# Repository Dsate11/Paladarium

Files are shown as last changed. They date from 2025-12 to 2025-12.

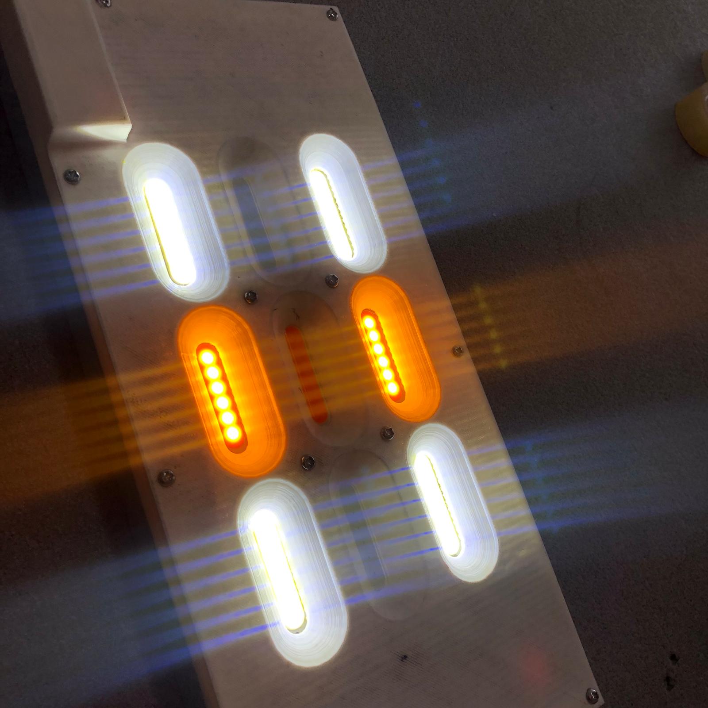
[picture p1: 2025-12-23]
images/leds_encendidos.jpg

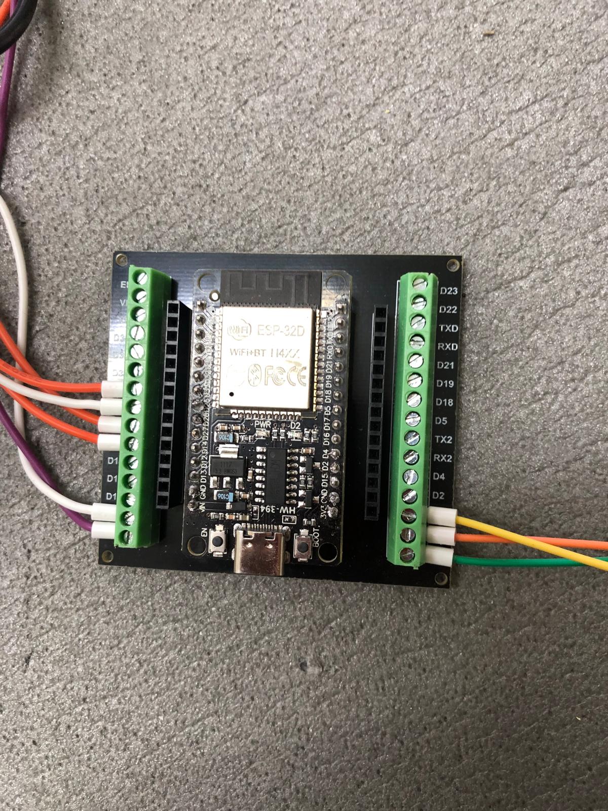
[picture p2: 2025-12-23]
images/f64968c0-9295-499c-b41d-dae9b5a2a1e8.jpg

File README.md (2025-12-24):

# 🌿 Paladarium - Sistema de Ecosistema Automatizado

Un proyecto de automatización para paladarium/terrario con control de clima, iluminación y monitoreo integrado con Home Assistant.

## 📋 Descripción

Este proyecto implementa un sistema completo de control y monitoreo para un paladarium, utilizando ESP32 y sensores diversos para mantener condiciones óptimas para plantas y animales. La integración con Home Assistant permite el control remoto y la visualización de datos en tiempo real.

## 🌡️ Sistema de Control de Clima

El paladarium cuenta con un sistema automatizado de control climático que gestiona temperatura, humedad y efectos de agua mediante sensores y actuadores conectados a un ESP32.

### Componentes del Sistema
- **Sensor DHT11**: Monitoreo de temperatura y humedad ambiental
- **Bombas de Agua**: 
  - Bomba de lluvia para simulación de precipitación
  - Bomba de cascada para circulación de agua
- **Relés**: Control de encendido/apagado de bombas y otros dispositivos

### Documentación Técnica Detallada
Para información completa sobre conexiones, configuración y diagramas de cableado, consulta la documentación en la carpeta `ecosistema_paladario/`:

- 📌 [**ESP32_PINOUT.md**](ecosistema_paladario/ESP32_PINOUT.md) - Asignación completa de pines del ESP32
- 📌 [**PINOUT.md**](ecosistema_paladario/PINOUT.md) - Diagrama general de conexiones
- 📌 [**CONEXIONES_DHT11.md**](ecosistema_paladario/CONEXIONES_DHT11.md) - Guía específica de conexión del sensor DHT11
- 📌 [**README_SISTEMA.md**](ecosistema_paladario/README_SISTEMA.md) - Descripción completa del sistema
- 📌 [**CONFIGURACION_WIFI_HA.md**](ecosistema_paladario/CONFIGURACION_WIFI_HA.md) - Configuración de WiFi y Home Assistant

## ✨ Características Futuras

- Sistema de alimentación automatizado
- Cámara para monitoreo visual
- Sistema de riego por goteo
- Control de CO2
- Análisis de datos históricos y predicciones

## 🚀 Tecnologías Utilizadas

- ESP32
- Home Assistant
- ESPHome
- Sensores DHT11
- Relés para control de dispositivos
- MQTT para comunicación

## 📦 Instalación

(Instrucciones de instalación pendientes)

## 🤝 Contribuciones

Las contribuciones son bienvenidas. Por favor, abre un issue o pull request para sugerencias o mejoras.

## 📄 Licencia

Este proyecto está bajo licencia MIT.

---

**Nota**: Este es un proyecto en desarrollo activo. La documentación y características se actualizan regularmente.

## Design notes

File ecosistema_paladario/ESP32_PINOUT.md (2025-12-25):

# Pinout ESP32 — Paladarium

## Tabla resumen

| Pin ESP32 | Nombre simbólico (código) | Función hardware |
|---|---|---|
| D33 | CALEFACCION_GPIO | Relé 4 (Calefacción) |
| D25 | BOMBA_LLUVIA_GPIO | Relé 1 (Bomba de lluvia) |
| D26 | BOMBA_CASCADA_GPIO | Relé 2 (Bomba cascada) |
| D27 | VENTILADOR_GPIO | Relé 3 (Ventilador) |
| D15 | DHT_GPIO | Sensor DHT11 |

---

## Diagrama de conexiones (visual)

```
                                    +----------------------+
                                    |     ESP32 DevKit     |
                          ________  +----------------------+
                         |        |  GPIO    | Dispositivo 
            Rele 4 <---- |  D33   | -------- | CALEFACCION  
            Rele 1 <---- |  D25   | -------- | BOMBA LLUVIA 
            Rele 2 <---- |  D26   | -------- | BOMBA CASCADA
            Rele 3 <---- |  D27   | -------- | VENTILADOR   
             DHT11 <---- |  D15   | -------- | SENSOR DHT11 
                         |________|
```

> **Nota:** Utiliza la referencia de pinout físico del modelo de ESP32 devkit que utilices para ubicar físicamente los GPIO referenciados.

---

## Recomendaciones y Advertencias

- Verifica la capacidad de corriente de cada pin antes de realizar cualquier conexión de carga.
- Los pines destinados a relés deben ser empleados con módulos de relé que admitan el voltaje de control TTL (3.3V en ESP32).
- Evita usar los pines listados para otras funciones para prevenir conflictos o comportamientos inesperados.
- Antes de energizar el sistema, comprueba dos veces las conexiones para evitar cortocircuitos o daños a la placa.
- No conectes cargas inductivas o de alto voltaje directamente al ESP32. Utiliza siempre relés o drivers adecuados.
- Consulta la hoja de datos de tu versión de la placa ESP32 y del sensor DHT11 para confirmar compatibilidades y conexiones de alimentación.

---

## Coincidencia con el código (src/main.c)

La definición de pines en `src/main.c` debe mantener la correlación 1 a 1 con la tabla presente en este documento. Cualquier modificación DEBE reflejarse en ambos lados para evitar inconsistencias o fallos de operación.

Ejemplo de definición:

```c
#define CALEFACCION_GPIO      33
#define BOMBA_LLUVIA_GPIO     25
#define BOMBA_CASCADA_GPIO    26
#define VENTILADOR_GPIO       27
#define DHT_GPIO              15
```

---

## Notas adicionales
- Ante cualquier duda sobre cambios de hardware, actualiza este documento junto con el firmware.
- Realiza pruebas funcionales antes de la puesta en marcha definitiva del paladarium.

---

Autor: Dsate11
Última actualización: 2025-12-25

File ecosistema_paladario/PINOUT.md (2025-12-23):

# 📌 PINOUT DETALLADO - Sistema Paladario ESP32

## 🔌 Conexiones del Sistema

### **Sensor DHT11 (Temperatura y Humedad)**

**Módulo de 3 pines (con resistencia pull-up integrada):**

**Cómo identificar los pines:**

1. **Por serigrafía en la PCB** (lo más común):
   - Busca las letras impresas en la tarjeta: `+`, `OUT`/`S`/`DATA`, `-`/`GND`
   - O pueden estar como: `VCC`, `DATA`, `GND`

2. **Por posición física** (vista desde el frente del sensor):
   ```
   ┌─────────────┐
   │   DHT11     │  ← Sensor azul con rejilla
   │  (rejilla)  │
   └─────────────┘
   │   │   │   │
   │   │   │   └─ Pin 4: GND (puede estar NC - no conectado)
   │   │   └───── Pin 3: NC (No Conectar) o no existe
   │   └───────── Pin 2: DATA (señal)
   └───────────── Pin 1: VCC (+)
   ```

3. **En módulos de 3 pines** (tarjeta verde/azul):
   ```
   Tarjeta PCB vista de frente:
   
   [+]  [OUT]  [-]     ← Serigrafía común
    │     │     │
   VCC  DATA  GND
   ```
   
   O también puede ser:
   ```
   [S]  [VCC]  [GND]   ← Otra disposición común
    │     │      │
   DATA  VCC   GND
   ```

**Conexión segura al ESP32:**
```
Módulo DHT11   →    ESP32
---------------------------------
+ / VCC        →    3.3V o 5V
OUT / S / DATA →    GPIO 4
- / GND        →    GND
```

**Nota:** Este módulo ya incluye la resistencia pull-up en la tarjeta, **NO necesitas agregar resistencia externa**

**🔍 Si no hay marcas visibles:**
- Con un multímetro, mide continuidad entre los pines del módulo y el sensor DHT11
- El pin GND del módulo debe tener continuidad con el pin 4 del sensor DHT11
- El pin VCC del módulo debe tener continuidad con el pin 1 del sensor DHT11

**Sensor DHT11 de 4 pines (sin módulo):**
```
DHT11 Sensor   →    Conexión
---------------------------------
VCC (Pin 1)    →    3.3V o 5V
DATA (Pin 2)   →    GPIO 4 + resistencia 10kΩ a VCC
NC (Pin 3)     →    No conectar
GND (Pin 4)    →    GND
```

---

### **Relé Bomba de Lluvia**
```
Módulo Relé    →    ESP32
---------------------------------
VCC            →    5V (VIN)
GND            →    GND
IN (Signal)    →    GPIO 25
```
**Conexión de la bomba:**
- COM (Común) → Cable de fase (220V) o positivo (12V)
- NO (Normalmente Abierto) → Bomba
- La bomba completa el circuito con Neutro (220V) o GND (12V)

---

### **Relé Bomba de Cascada**
```
Módulo Relé    →    ESP32
---------------------------------
VCC            →    5V (VIN)
GND            →    GND
IN (Signal)    →    GPIO 26
```
**Conexión de la bomba:**
- COM (Común) → Cable de fase (220V) o positivo (12V)
- NO (Normalmente Abierto) → Bomba
- La bomba completa el circuito con Neutro (220V) o GND (12V)

---

## 🔧 Resumen de Pines ESP32 Utilizados

| Pin GPIO | Función | Tipo | Descripción |
|---|---|---|---|
| GPIO 4 | Sensor DHT11 DATA | INPUT | Lectura temperatura/humedad |
| GPIO 25  | Control Bomba Lluvia | OUTPUT  | Activa/desactiva relé lluvia |
| GPIO 26  | Control Bomba Cascada | OUTPUT  | Activa/desactiva relé cascada |
| 3.3V | Alimentación sensores | POWER | Para DHT11 |
| 5V (VIN) | Alimentación relés | POWER | Para módulos relé |
| GND | Tierra común | GROUND  | Compartida todos los componentes |

---

## 🎨 Diagrama de Conexión Simplificado

```
                    ┌─────────────────┐
                    │     ESP32       │
                    │  DevKit V4      │
                    └─────────────────┘
                            │
        ┌───────────────────┼───────────────────┐
        │                   │                   │
    GPIO 4             GPIO 25            GPIO 26
        │                   │                   │
   ┌────▼────┐         ┌────▼────┐        ┌────▼────┐
   │ DHT11   │         │ RELÉ 1  │        │ RELÉ 2  │
   │ Temp/Hum│         │ LLUVIA  │        │ CASCADA │
   └─────────┘         └────┬────┘        └────┬────┘
                            │                  │
                       ┌────▼────┐        ┌────▼────┐
                       │ BOMBA   │        │ BOMBA   │
                       │ LLUVIA  │        │ CASCADA │
                       └─────────┘        └─────────┘
```

---

## ⚠️ ADVERTENCIAS DE SEGURIDAD

### **Si usas 220V AC:**
1. ⚡ **PELIGRO:** Desconecta siempre la alimentación antes de manipular
2. Usa módulos relés con optoacoplador para aislamiento
3. Verifica que los relés soporten la corriente de tus bombas
4. Instala en caja eléctrica adecuada con protección IP65+ para humedad
5. Considera usar un interruptor diferencial (GFCI/RCD)

### **Si usas 12V DC:**
1. Mucho más seguro para ambientes húmedos
2. Usa fuente de alimentación de capacidad suficiente
3. Verifica polaridad correcta en las bombas
4. Los relés también deben soportar la corriente DC

---

## 🔋 Alimentación del Sistema

**Opción 1 - USB:**
- ESP32 alimentado por cable USB (5V)
- Limitado a corrientes bajas en los GPIOs
- Los relés necesitan fuente externa de 5V

**Opción 2 - Fuente Externa:**
- Alimentar VIN con 5-12V DC regulados
- Permite mayor corriente para módulos adicionales
- Compartir GND común entre ESP32 y fuente

---

## 📝 Notas Adicionales

- Los GPIOs del ESP32 entregan **3.3V lógico**
- Corriente máxima por pin: **40mA** (recomendado: 20mA)
- Los módulos relé suelen necesitar **5V** y ~70-80mA
- El DHT11 consume aproximadamente **2.5mA** en standby
- Pines GPIO 25 y 26 son seguros para usar (no tienen funciones especiales críticas)
- GPIO 4 también es seguro (no afecta el boot del ESP32)

---

## 🛠️ Lista de Materiales

| Cantidad | Componente | Especificaciones |
|---|---|---|
| 1 | ESP32 DevKit V4 | 30 pines |
| 1 | Módulo DHT11 | Temp/Humedad, 3 pines |
| 2 | Módulo Relé 1 canal | 5V, optoacoplado |
| 2 | Bomba de agua sumergible | 12V o 220V según diseño |
| 1 | Fuente de alimentación | 5V/2A o 12V/2A |
| - | Cables dupont/jumper | Macho-hembra |
| - | Protoboard o PCB | Para montaje |

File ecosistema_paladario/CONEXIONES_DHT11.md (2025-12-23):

# 🔌 ESQUEMA DE CONEXIONES - DHT11 + ESP32

## 📋 Módulo DHT11 de 3 Pines

```
Vista del módulo DHT11 (mirando de frente al sensor azul):

┌─────────────────────────┐
│   Módulo DHT11 PCB      │
│   ┌───────────────┐     │
│   │   DHT11       │     │  ← Sensor azul con rejilla
│   │  (rejilla)    │     │
│   └───────────────┘     │
│                         │
└─────────────────────────┘
   │      │      │
   │      │      └─── [-] GND    → Color cable: NEGRO o MARRÓN
   │      └────────── [OUT] DATA → Color cable: AMARILLO o VERDE
   └───────────────── [+] VCC    → Color cable: ROJO

Serigrafía común en el módulo:
┌───┬─────┬─────┐
│ + │ OUT │  -  │
└───┴─────┴─────┘
 o también:
┌─────┬──────┬─────┐
│ VCC │ DATA │ GND │
└─────┴──────┴─────┘
```

---

## 🔧 ESP32 DevKit V4 - Vista de Pines

```
ESP32 DevKit V4 (30 pines)
Puerto USB hacia ARRIBA ↑

Lado IZQUIERDO          Lado DERECHO
════════════════        ════════════════
3V3  ←─ VCC DHT11      GND
EN                      GPIO 23
GPIO 36 (VP)           GPIO 22
GPIO 39 (VN)           GPIO 1 (TX0)
GPIO 34                 GPIO 3 (RX0)
GPIO 35                 GPIO 21
GPIO 32                 GPIO 19
GPIO 33 ← CALEFACCIÓN  GPIO 18
GPIO 25 ← BOMBA LLUVIA GPIO 5
GPIO 26 ← BOMBA CASCA. GPIO 17
GPIO 27 ← VENTILADOR   GPIO 16
GPIO 14                 GPIO 4  ←─ DATA DHT11 ⭐
GPIO 12                 GPIO 0
GPIO 13                 GPIO 2  ←─ (prueba alternativa)
GND  ←─ GND DHT11      GPIO 15
VIN                     GND
```

---

## ✅ CONEXIÓN CORRECTA

```
┌──────────────────────┐              ┌──────────────────────┐
│  MÓDULO DHT11        │              │    ESP32 DevKit V4   │
│                      │              │                      │
│  ┌────────────┐      │              │                      │
│  │  DHT11     │      │              │      [USB]           │
│  │ (sensor)   │      │              │       ___            │
│  └────────────┘      │              │      |   |           │
│                      │              │                      │
│   [+]  [OUT]  [-]    │              │                      │
│    │     │     │     │              │                      │
└────┼─────┼─────┼─────┘              └──────────────────────┘
     │     │     │                          │     │     │
     │     │     └──────────────────────────┤     │     │
     │     │         CABLE NEGRO/MARRÓN     │     │     │
     │     │                               GND    │     │
     │     │                                      │     │
     │     └────────────────────────────────────┐ │     │
     │              CABLE AMARILLO/VERDE        │ │     │
     │                                       GPIO 4     │
     │                                          │ │     │
     └──────────────────────────────────────────┼─┤     │
                  CABLE ROJO                    │ │     │
                                               3V3 │     │
                                                  │     │
                                                 GND   3V3
```

---

## 🔍 VERIFICACIÓN DE CONEXIONES

### ✓ Lista de verificación:

1. **Cable ROJO (VCC)**
   - Desde pin [+] del DHT11
   - Hasta pin **3V3** del ESP32 (lado izquierdo, arriba del todo)
   - ⚠️ NO usar 5V, usar 3.3V

2. **Cable NEGRO/MARRÓN (GND)**
   - Desde pin [-] del DHT11
   - Hasta pin **GND** del ESP32 (hay varios, usa el del lado izquierdo cerca del 3V3)

3. **Cable AMARILLO/VERDE (DATA)**
   - Desde pin [OUT] o [DATA] del DHT11
   - Hasta pin **GPIO 4** del ESP32 (lado derecho, posición 12 desde abajo)
   - ⚠️ Este es el cable que está dando problemas

---

## ⚠️ ERRORES COMUNES

### ❌ Error 1: Pines invertidos
```
INCORRECTO:
DHT11 [-] → ESP32 3V3   ✗ MAL!
DHT11 [+] → ESP32 GND   ✗ MAL!
```

### ❌ Error 2: DATA conectado a GND
```
Tu problema actual:
DHT11 [OUT] → hace corto con GND
Resultado: Pin siempre en LOW
```

### ❌ Error 3: VCC sin conectar
```
DHT11 [+] → sin conexión
Resultado: Pin siempre en HIGH, no responde
```

---

## 🔧 DIAGNÓSTICO CON MULTÍMETRO

### Con el DHT11 conectado al ESP32 encendido:

1. **Medir voltaje VCC:**
   ```
   Multímetro en modo DC Voltaje
   Punta ROJA  → Pin [+] del DHT11
   Punta NEGRA → Pin [-] del DHT11
   
   Debería leer: 3.3V ± 0.1V
   Si lee 0V: VCC no conectado
   ```

2. **Medir voltaje DATA en reposo:**
   ```
   Multímetro en modo DC Voltaje
   Punta ROJA  → Pin [OUT] del DHT11
   Punta NEGRA → Pin [-] del DHT11
   
   Debería leer: 3.3V (por pull-up)
   Si lee 0V: DATA en corto con GND ← TU PROBLEMA
   ```

3. **Verificar continuidad (con ESP32 APAGADO):**
   ```
   Multímetro en modo CONTINUIDAD (beep)
   
   TEST 1:
   Punta 1 → Pin [OUT] del DHT11
   Punta 2 → Pin [-] del DHT11
   
   NO debe hacer BEEP (no debe haber continuidad)
   Si hace BEEP: Hay cortocircuito ← TU PROBLEMA
   
   TEST 2:
   Punta 1 → Pin [+] del DHT11
   Punta 2 → Pin [-] del DHT11
   
   NO debe hacer BEEP
   Si hace BEEP: Cortocircuito VCC-GND
   ```

---

## 🔨 SOLUCIÓN AL PROBLEMA ACTUAL

### Tu sensor muestra: **Pin en LOW permanente**

**Causa:** El pin DATA está en cortocircuito con GND

**Posibles soluciones:**

1. **Revisar soldadura en el módulo DHT11:**
   - ¿Hay un puente de estaño entre pines OUT y GND?
   - Dessoldar y volver a soldar con cuidado

2. **Verificar el cable DATA:**
   - ¿El aislante está dañado?
   - ¿Toca algún otro cable o componente?

3. **Probar con cables diferentes:**
   - Puede que el cable tenga daño interno

4. **Reemplazar el sensor DHT11:**
   - El sensor puede estar dañado internamente

---

## 📸 FOTO DE REFERENCIA DE PINES

```
Módulo DHT11 típico visto desde arriba:

     ╔════════════════╗
     ║  DHT11 MODULE  ║
     ║  ╔══════════╗  ║
     ║  ║ ░░░░░░░░ ║  ║  ← Rejilla del sensor
     ║  ║ ░░DHT11░ ║  ║
     ║  ║ ░░░░░░░░ ║  ║
     ║  ╚══════════╝  ║
     ║                ║
     ║  +   OUT   -   ║  ← Serigrafía
     ╚════════════════╝
        │    │    │
      ROJO AMARI NEGRO
      3V3  GPIO4  GND
```

---

## 🎯 CÓDIGO ACTUAL

El código actual está configurado para **GPIO 2** (prueba).

Para volver a GPIO 4 (correcto según hardware), cambiar en `main.c`:
```c
#define DHT_GPIO 4  // Pin correcto según documentación
```

---

## 📞 PRÓXIMOS PASOS

1. ✓ Apaga el ESP32
2. ✓ Desconecta el cable DATA (amarillo)
3. ✓ Mide con multímetro:
   - Continuidad entre DATA y GND del módulo DHT11
   - Voltaje entre VCC y GND (debería ser 3.3V con ESP32 encendido)
4. ✓ Si hay cortocircuito, revisa la soldadura del módulo
5. ✓ Reconecta y prueba de nuevo

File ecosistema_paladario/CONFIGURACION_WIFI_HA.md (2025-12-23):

# 🌐 Guía de Configuración WiFi y Home Assistant

## 📡 Configuración WiFi

### 1. Editar credenciales WiFi

Abre el archivo `src/wifi_config.h` y modifica:

```c
#define WIFI_SSID ""        // Nombre de tu red WiFi
#define WIFI_PASSWORD ""  // Contraseña de tu WiFi
```

### 2. Compilar y subir

```bash
cd "c:\Users\diego\OneDrive\Documentos\PlatformIO\Projects\ecosistema_paladario"
pio run --target upload
pio device monitor
```

### 3. Obtener la IP del ESP32

En el monitor serial verás algo como:
```
I (2345) PALADARIO: IP obtenida: 192.168.1.150
```

Anota esta IP para acceder al panel web.

---

## 🖥️ Acceso al Panel Web

### Desde cualquier navegador en tu red local:

```
http://192.168.1.150
```
(Usa la IP que obtuviste en el paso anterior)

### Características del Panel Web:

✅ **Ver en tiempo real:**
- Temperatura actual
- Humedad actual
- Estado de bombas (ON/OFF)

✅ **Controlar:**
- Encender/apagar bomba de lluvia con un click
- Encender/apagar bomba de cascada con un click

✅ **Auto-actualización:**
- La página se recarga cada 10 segundos automáticamente

---

## 🏠 Integración con Home Assistant

### Prerequisitos:

1. **Tener Home Assistant instalado y funcionando**
2. **MQTT Broker configurado** (Mosquitto addon recomendado)

### Paso 1: Configurar MQTT en Home Assistant

#### Instalar Mosquitto Broker:

1. Ve a `Settings` → `Add-ons` → `Add-on Store`
2. Busca **"Mosquitto broker"**
3. Click en `Install`
4. Una vez instalado, ve a la pestaña `Configuration`
5. Habilita estas opciones:
   ```yaml
   logins:
     - username: homeassistant
       password: tu_password_mqtt
   ```
6. Click en `Save` y luego `Start`

#### Configurar integración MQTT:

1. Ve a `Settings` → `Devices & Services`
2. Click en `Add Integration`
3. Busca **"MQTT"**
4. Configura:
   - Broker: `localhost` (o la IP de tu Home Assistant)
   - Port: `1883`
   - Username: `homeassistant`
   - Password: `tu_password_mqtt`

### Paso 2: Configurar el ESP32

Edita `src/wifi_config.h`:

```c
#define MQTT_BROKER "192.168.1.100"    // IP de tu Home Assistant
#define MQTT_PORT 1883
#define MQTT_USER "homeassistant"      // Usuario MQTT
#define MQTT_PASS "tu_password_mqtt"   // Contraseña MQTT
```

### Paso 3: Compilar y subir

```bash
pio run --target upload
```

### Paso 4: Verificar en Home Assistant

Después de unos segundos, deberías ver automáticamente en Home Assistant:

**Dispositivos detectados:**
- 🌡️ **Paladario Temperatura** (sensor)
- 💧 **Paladario Humedad** (sensor)
- 💦 **Bomba Lluvia** (switch)
- 🌊 **Bomba Cascada** (switch)

**¿Dónde encontrarlos?**
1. Ve a `Settings` → `Devices & Services`
2. Click en `MQTT`
3. Deberías ver un dispositivo llamado **"Paladario"**

---

## 🎨 Crear Tarjeta en Home Assistant

### Dashboard personalizado:

```yaml
type: vertical-stack
cards:
  - type: entities
    title: 🌿 Paladario
    entities:
      - entity: sensor.paladario_temperatura
        name: Temperatura
        icon: mdi:thermometer
      - entity: sensor.paladario_humedad
        name: Humedad
        icon: mdi:water-percent
      - entity: switch.bomba_lluvia
        name: Bomba Lluvia
        icon: mdi:water
      - entity: switch.bomba_cascada
        name: Bomba Cascada
        icon: mdi:waterfall
  - type: history-graph
    title: Historial
    entities:
      - sensor.paladario_temperatura
      - sensor.paladario_humedad
    hours_to_show: 24
```

**Cómo agregar:**
1. Ve a tu Dashboard
2. Click en los 3 puntos (arriba derecha) → `Edit Dashboard`
3. Click en `+ Add Card`
4. Selecciona `Manual` abajo
5. Pega el código YAML anterior
6. Click en `Save`

---

## 🔧 API REST Endpoints

### Obtener estado completo:

```bash
GET http://192.168.1.150/api/status
```

**Respuesta JSON:**
```json
{
  "temperatura": 25.5,
  "humedad": 68.0,
  "bomba_lluvia": true,
  "bomba_cascada": false
}
```

### Toggle Bomba Lluvia:

```bash
GET http://192.168.1.150/api/lluvia/toggle
```

### Toggle Bomba Cascada:

```bash
GET http://192.168.1.150/api/cascada/toggle
```

---

## 📊 Tópicos MQTT

### Sensores (lectura):

```
paladario/sensor/temperatura/state    → "25.5"
paladario/sensor/humedad/state        → "68.0"
```

### Switches Estado (lectura):

```
paladario/switch/bomba_lluvia/state   → "ON" o "OFF"
paladario/switch/bomba_cascada/state  → "ON" o "OFF"
```

### Switches Comandos (escritura):

```
paladario/switch/bomba_lluvia/set     ← "ON" o "OFF"
paladario/switch/bomba_cascada/set    ← "ON" o "OFF"
```

---

## 🎯 Automatizaciones en Home Assistant

### Ejemplo 1: Notificación de temperatura alta

```yaml
automation:
  - alias: "Alerta Temperatura Alta Paladario"
    trigger:
      - platform: numeric_state
        entity_id: sensor.paladario_temperatura
        above: 30
    action:
      - service: notify.mobile_app
        data:
          title: "⚠️ Temperatura Alta"
          message: "El paladario tiene {{ states('sensor.paladario_temperatura') }}°C"
```

### Ejemplo 2: Encender lluvia automáticamente

```yaml
automation:
  - alias: "Lluvia Automática Paladario"
    trigger:
      - platform: numeric_state
        entity_id: sensor.paladario_humedad
        below: 50
    action:
      - service: switch.turn_on
        target:
          entity_id: switch.bomba_lluvia
```

### Ejemplo 3: Cascada solo de día

```yaml
automation:
  - alias: "Cascada Solo de Día"
    trigger:
      - platform: sun
        event: sunrise
    action:
      - service: switch.turn_on
        target:
          entity_id: switch.bomba_cascada
  
  - alias: "Apagar Cascada de Noche"
    trigger:
      - platform: sun
        event: sunset
    action:
      - service: switch.turn_off
        target:
          entity_id: switch.bomba_cascada
```

---

## 🔍 Solución de Problemas

### No aparece en Home Assistant:

1. **Verificar MQTT:**
   - Ve a `Settings` → `Devices & Services` → `MQTT`
   - Click en `Configure` → `Listen to a topic`
   - Escribe: `paladario/#`
   - Deberías ver mensajes llegando

2. **Verificar logs del ESP32:**
   ```bash
   pio device monitor
   ```
   Busca: `MQTT conectado` y `Descubrimiento MQTT enviado`

3. **Reiniciar Home Assistant:**
   - `Settings` → `System` → `Restart`

### No puedo acceder al panel web:

1. Verificar que estés en la misma red WiFi
2. Hacer ping a la IP del ESP32
3. Verificar firewall/router
4. Revisar logs en el monitor serial

### MQTT no conecta:

1. Verificar IP correcta del broker
2. Verificar usuario y contraseña
3. Verificar que Mosquitto esté corriendo
4. Revisar puerto 1883 abierto

---

## 📱 Aplicación Móvil Home Assistant

Con la app de Home Assistant en tu móvil puedes:

✅ Ver temperatura y humedad en tiempo real
✅ Controlar las bombas desde cualquier lugar
✅ Recibir notificaciones
✅ Widgets en pantalla de inicio
✅ Control por voz con Google Assistant/Alexa

**Descargar:**
- iOS: App Store → "Home Assistant"
- Android: Play Store → "Home Assistant"

---

## 🎉 ¡Todo Listo!

Ahora tienes:

✅ Panel web accesible desde cualquier navegador
✅ Integración completa con Home Assistant
✅ Control desde móvil
✅ Automatizaciones inteligentes
✅ Historial de datos
✅ Notificaciones

**Próximos pasos opcionales:**
- Agregar más sensores (luz, pH, etc.)
- Crear escenas personalizadas
- Integrar con Google Home/Alexa
- Agregar cámara para ver el paladario

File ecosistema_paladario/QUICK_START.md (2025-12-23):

# 🚀 QUICK START - Paladario WiFi

## 📝 Pasos Rápidos

### 1. Configurar WiFi
Edita `src/wifi_config.h`:
```c
#define WIFI_SSID "TU_RED_WIFI"
#define WIFI_PASSWORD "TU_CONTRASEÑA"
```

### 2. Subir Código
```bash
pio run --target upload
pio device monitor
```

### 3. Obtener IP
Busca en el monitor serial:
```
I (2345) PALADARIO: IP obtenida: 192.168.1.150
```

### 4. Acceder desde Navegador
```
http://192.168.1.150
```

## 🏠 Home Assistant (Opcional)

### 1. Instalar Mosquitto Broker en HA
- Settings → Add-ons → Mosquitto broker → Install

### 2. Configurar MQTT en `src/wifi_config.h`
```c
#define MQTT_BROKER "192.168.1.100"  // IP de Home Assistant
#define MQTT_USER "homeassistant"
#define MQTT_PASS "tu_password"
```

### 3. Listo!
Los dispositivos aparecerán automáticamente en Home Assistant.

## 📊 Endpoints API

- `http://IP/` → Panel web
- `http://IP/api/status` → JSON con todos los datos
- `http://IP/api/lluvia/toggle` → Toggle bomba lluvia
- `http://IP/api/cascada/toggle` → Toggle bomba cascada

## 🔧 Conexiones Físicas

```
DHT11:    VCC→3V3,  DATA→GPIO4,   GND→GND
Relé 1:   VCC→VIN,  IN→GPIO25,    GND→GND  (Lluvia)
Relé 2:   VCC→VIN,  IN→GPIO26,    GND→GND  (Cascada)
```

¡Listo para usar! 🎉

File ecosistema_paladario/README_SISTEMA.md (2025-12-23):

# 📋 Documentación del Sistema de Control del Paladario

## 🎯 Funcionalidades Implementadas

### 1. **Monitoreo de Temperatura y Humedad**
- Sensor: DHT11 en GPIO 4
- Frecuencia de lectura: Cada 5 segundos
- Muestra en consola: Temperatura en °C y Humedad en %

### 2. **Control Automático de Bomba de Lluvia**
- Pin de control: GPIO 25
- Lógica automática:
  - Si humedad < 60% → Activa bomba de lluvia
  - Si humedad > 80% → Desactiva bomba de lluvia
- Se puede controlar manualmente modificando el código

### 3. **Control de Bomba de Cascada**
- Pin de control: GPIO 26
- Ciclo automático:
  - 30 minutos ENCENDIDA
  - 30 minutos APAGADA
  - Ciclo infinito

### 4. **Monitoreo en Tiempo Real**
- Cada 10 segundos muestra en el monitor serial:
  - Temperatura actual
  - Humedad actual
  - Estado de bomba lluvia (ON/OFF)
  - Estado de bomba cascada (ON/OFF)

---

## 🔧 Configuración Actual

```c
// Pines definidos
GPIO 4  → Sensor DHT11 (DATA)
GPIO 25 → Relé bomba lluvia (señal)
GPIO 26 → Relé bomba cascada (señal)

// Umbrales de humedad
Humedad baja: < 60%  → Activa lluvia
Humedad alta: > 80%  → Desactiva lluvia

// Tiempos de ciclo cascada
30 minutos ON
30 minutos OFF
```

---

## ⚙️ Personalización

### Cambiar umbrales de humedad:
Edita en `src/main.c`, función `task_leer_sensor()`:
```c
if (humedad < 60.0 && !bomba_lluvia_activa) {  // Cambiar 60.0
    control_bomba_lluvia(true);
} else if (humedad > 80.0 && bomba_lluvia_activa) {  // Cambiar 80.0
    control_bomba_lluvia(false);
}
```

### Cambiar ciclo de cascada:
Edita en `src/main.c`, función `task_ciclo_cascada()`:
```c
vTaskDelay(pdMS_TO_TICKS(30 * 60 * 1000));  // 30 minutos = 30*60*1000 ms
// Cambiar el número 30 por los minutos deseados
```

### Cambiar frecuencia de lectura del sensor:
Edita en `src/main.c`, función `task_leer_sensor()`:
```c
vTaskDelay(pdMS_TO_TICKS(5000));  // 5000 ms = 5 segundos
// Cambiar 5000 por los milisegundos deseados
```

---

## 📊 Estructura del Código

```
src/
├── main.c       → Programa principal
├── dht11.c      → Driver del sensor DHT11
└── dht11.h      → Declaraciones del driver DHT11

Funciones principales en main.c:
├── config_gpio()           → Configura pines como entrada/salida
├── control_bomba_lluvia()  → Enciende/apaga bomba lluvia
├── control_bomba_cascada() → Enciende/apaga bomba cascada
├── task_leer_sensor()      → Lee DHT11 cada 5 seg
├── task_ciclo_cascada()    → Ciclo automático cascada
├── task_mostrar_estado()   → Muestra estado cada 10 seg
└── app_main()              → Inicializa todo
```

---

## 🚀 Cómo Usar

### 1. Compilar:
```bash
cd "c:\Users\diego\OneDrive\Documentos\PlatformIO\Projects\ecosistema_paladario"
pio run
```

### 2. Subir al ESP32:
```bash
pio run --target upload
```

### 3. Ver monitor serial:
```bash
pio device monitor
```

### 4. Salida esperada en el monitor:
```
I (308) PALADARIO: Iniciando sistema de control de Paladario
I (308) PALADARIO: GPIOs configurados correctamente
I (308) PALADARIO: Sistema iniciado correctamente
I (308) PALADARIO: Iniciando lectura de sensor DHT11...
I (308) PALADARIO: Iniciando ciclo de cascada...
I (308) PALADARIO: Bomba cascada: ENCENDIDA
I (2308) PALADARIO: Temperatura: 25.0°C, Humedad: 55.0%
I (2308) PALADARIO: Humedad baja, activando efecto lluvia
I (2308) PALADARIO: Bomba lluvia: ENCENDIDA
I (10308) PALADARIO: === ESTADO PALADARIO ===
I (10308) PALADARIO: Temperatura: 25.0°C
I (10308) PALADARIO: Humedad: 55.0%
I (10308) PALADARIO: Bomba lluvia: ON
I (10308) PALADARIO: Bomba cascada: ON
I (10308) PALADARIO: ========================
```

---

## 🔌 Conexiones Físicas

```
DHT11 Módulo:
  VCC/+ → 3V3 del ESP32
  DATA  → GPIO 4
  GND/- → GND del ESP32

Relé Bomba Lluvia:
  VCC → VIN del ESP32 (5V)
  IN  → GPIO 25
  GND → GND del ESP32

Relé Bomba Cascada:
  VCC → VIN del ESP32 (5V)
  IN  → GPIO 26
  GND → GND del ESP32
```

---

## ⚠️ Notas Importantes

1. **Sensibilidad del DHT11:**
   - No leerlo más rápido que cada 2 segundos
   - Puede dar errores ocasionales (es normal)
   - El código reintenta automáticamente en el siguiente ciclo

2. **Control de relés:**
   - Los relés se activan con señal HIGH (3.3V)
   - Asegúrate que sean módulos con optoacoplador
   - Verifica que soporten la carga de tus bombas

3. **Alimentación:**
   - ESP32 consume ~500mA máximo
   - Cada relé consume ~70mA
   - DHT11 consume ~2.5mA
   - Total: ~650mA (usar fuente de 1A mínimo)

4. **Protección:**
   - Los relés protegen el ESP32 de la carga de las bombas
   - No conectar bombas directamente al ESP32
   - Siempre usar relés o transistores

---

## 🐛 Solución de Problemas

### Error al leer sensor DHT11:
- Verificar conexiones (VCC, DATA, GND)
- Verificar que el pin DATA esté en GPIO 4
- Sensor puede tardar hasta 2 segundos en responder

### Bombas no se activan:
- Verificar que los relés estén alimentados (VIN = 5V)
- Verificar conexiones de señal (GPIO 25 y 26)
- Probar con LED en lugar de relé para depurar

### ESP32 no compila/sube:
- Verificar que esté conectado el cable USB
- Presionar botón BOOT al subir código
- Verificar puerto COM en Device Manager

---

## 📝 Próximas Mejoras Opcionales

1. **Control WiFi:**
   - Añadir servidor web para control remoto
   - Ver datos en tiempo real desde navegador

2. **Pantalla OLED:**
   - Mostrar temperatura y humedad en pantalla
   - Ver estado de bombas sin PC

3. **Registro de datos:**
   - Guardar histórico en tarjeta SD
   - Gráficas de temperatura/humedad

4. **Sensor de nivel de agua:**
   - Detectar si hay suficiente agua
   - Apagar bombas si el nivel es bajo

5. **RTC (Reloj de Tiempo Real):**
   - Programar horarios específicos
   - Ciclos basados en hora del día

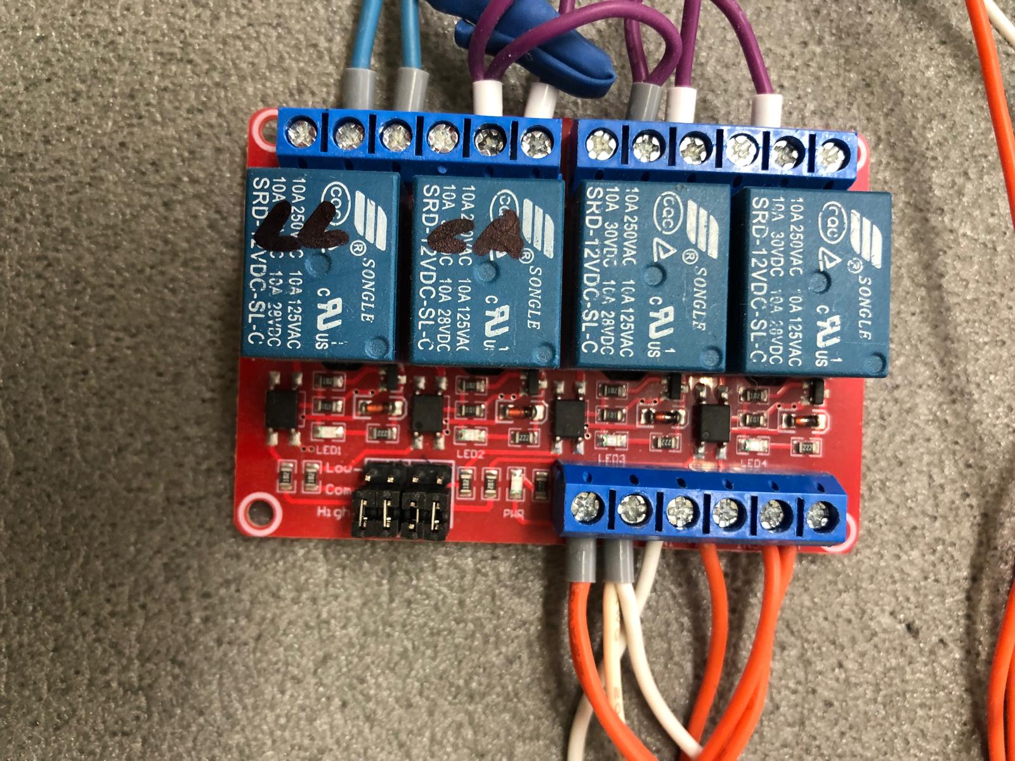
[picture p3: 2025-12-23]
images/1d93e1f7-10f8-4691-8a15-eafca741597e.jpg

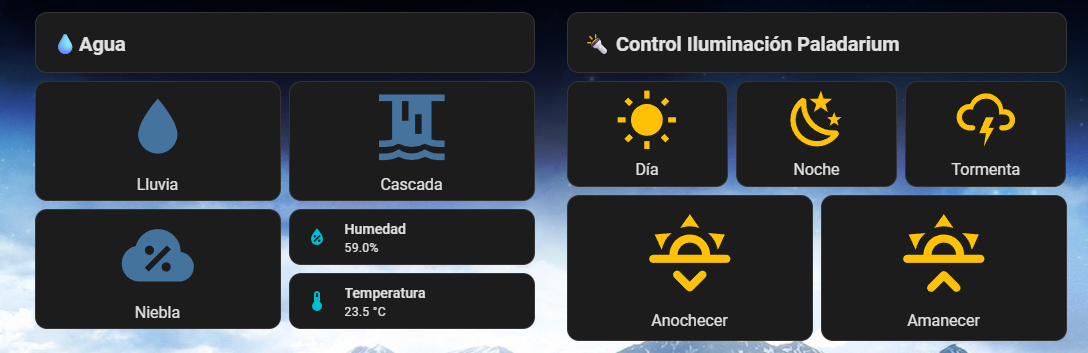
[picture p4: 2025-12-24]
Captura de pantalla 2025-12-24 112836.png

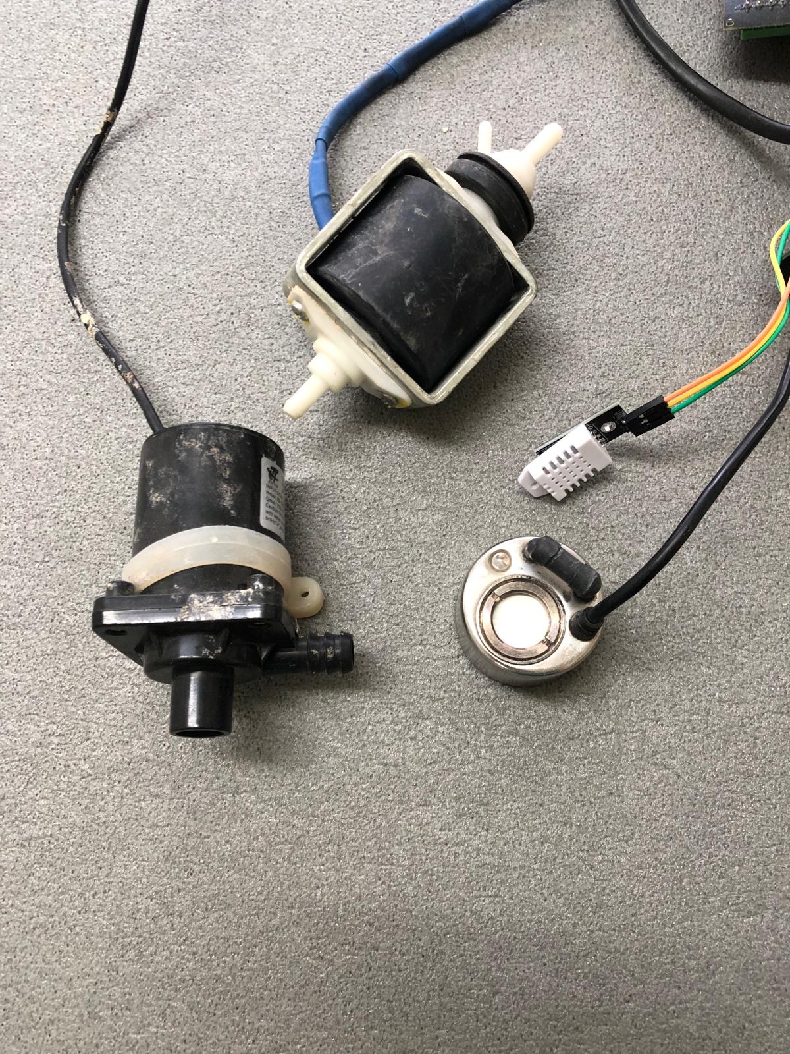
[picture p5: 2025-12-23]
images/88e4d60d-8d1c-486a-88bf-cecc8cd80386.jpg

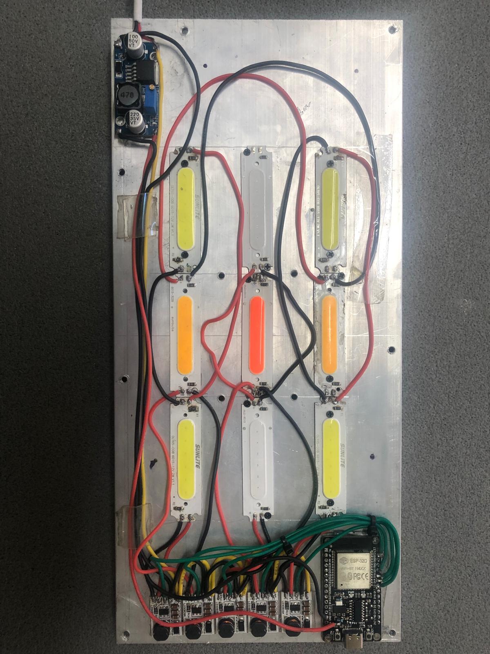
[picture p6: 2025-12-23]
images/conexiones_completas.jpg

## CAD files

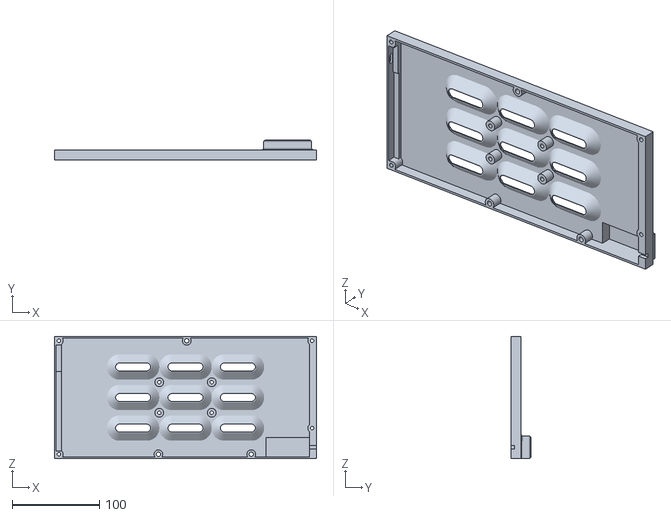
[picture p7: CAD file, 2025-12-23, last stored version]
Iluminacion Paladario/Tapa iluminacion.stl
300.0 x 22.5 x 140.0

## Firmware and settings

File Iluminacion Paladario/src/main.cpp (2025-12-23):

#include <Arduino.h>
#include <WiFi.h>
#include <Preferences.h>
#include <WiFiClient.h>
#include <PubSubClient.h>
#include <WebServer.h>
#include <ESPmDNS.h>

// Pines asignados
const int pinBlanco1 = 5;
const int pinNaranja = 18;
const int pinAzul    = 19;
const int pinBlanco2 = 22;

// Canales PWM
const int canalBlanco1 = 0;
const int canalNaranja = 1;
const int canalAzul    = 2;
const int canalBlanco2 = 3;

// Resolución PWM
const int frecuencia = 20000; // Aumentado a 20 kHz para evitar parpadeo
const int resolucion = 8; // 0–255

// Prototipos
void modoNoche();
void modoDia();
void enterStorm();
void handleStorm();
void enterAmanecer();
void handleAmanecer();
void showMenu();
void handleSerialInput();
void showSettingsMenu();
// Prototipos para sincronización y triggers
bool syncTimeAndCalculateSun();
void checkSunTriggersNow();
void applyDayNightBasedOnSun();
// Prototipos para modo anochecer
void enterAnochecer();
void handleAnochecer();
// Prototipos para persistencia y MQTT
void loadSavedWiFi();
void loadMQTTConfig();
void saveMQTTConfig();
bool connectMQTT();
void handleMQTT();
void publishState();
void mqttCallback(char* topic, byte* payload, unsigned int length);
// Prototipos para servidor web
void setupWebServer();
void handleRoot();
void handleConfig();
void handleConfigSave();
void handleStatus();
void handleNotFound();

// Nombre mDNS del dispositivo
const char* mdnsName = "iluminacion";

// Botón para alternar modos (usa pull-up)
const int pinBoton = 13;
const unsigned long debounceDelay = 50; // ms

// Estado del botón
int lastButtonState = HIGH;
int buttonState = HIGH;
unsigned long lastDebounceTime = 0;
// Buffer para entrada Serial por línea
String serialBuffer = "";
// Modo de ajustes
bool inSettings = false;
String pendingSetting = ""; // indica qué ajuste está esperando valor

// WiFi / Hora / Geolocalización para amanecer/anochecer
char wifiSsid[64] = "";
char wifiPass[64] = "";
// Preferencias para persistencia
Preferences prefs;

// MQTT
char mqttHost[128] = "";
int mqttPort = 1883;
char mqttTopic[128] = "iluminacion";
WiFiClient espClient;
PubSubClient mqttClient(espClient);
unsigned long lastMqttReconnectAttempt = 0;
WebServer webServer(80);
double locationLat = 0.0;
double locationLon = 0.0;
int timezoneOffsetHours = 0; // horas respecto a UTC
bool autoSunEnabled = false; // si true, sincroniza y activa modos en sunrise/sunset

// Sunrise/sunset calculados (minutos desde medianoche local)
int sunriseMinutes = -1;
int sunsetMinutes = -1;
int lastSunCalcDay = -1; // día del año cuando calculamos últimos valores
bool sunriseTriggeredToday = false;
bool sunsetTriggeredToday = false;

// Helpers (deg/rad)
static double degToRad(double deg) { return deg * M_PI / 180.0; }
static double radToDeg(double rad) { return rad * 180.0 / M_PI; }

// Calcula sunrise/sunset en minutos locales usando algoritmo aproximado (NOAA)
void calculateSunriseSunset(int year, int month, int day, double lat, double lon, int tzHours, int &sunriseMin, int &sunsetMin) {
  // día del año
  tm timeinfo = {};
  timeinfo.tm_year = year - 1900;
  timeinfo.tm_mon = month - 1;
  timeinfo.tm_mday = day;
  mktime(&timeinfo);
  int dayOfYear = timeinfo.tm_yday + 1;

  double gamma = 2.0 * M_PI / 365.0 * (dayOfYear - 1 + ((12 - tzHours) / 24.0));

  double eqTime = 229.18 * (0.000075 + 0.001868 * cos(gamma) - 0.032077 * sin(gamma) - 0.014615 * cos(2*gamma) - 0.040849 * sin(2*gamma));
  double solarDec = 0.006918 - 0.399912 * cos(gamma) + 0.070257 * sin(gamma) - 0.006758 * cos(2*gamma) + 0.000907 * sin(2*gamma) - 0.002697 * cos(3*gamma) + 0.00148 * sin(3*gamma);

  double latRad = degToRad(lat);
  double haArg = (cos(degToRad(90.833)) / (cos(latRad) * cos(solarDec)) - tan(latRad) * tan(solarDec));
  if (haArg > 1.0 || haArg < -1.0) {
    // Polar day/night, set as disabled
    sunriseMin = -1;
    sunsetMin = -1;
    return;
  }
  double hourAngle = acos(haArg);

  double solarNoon = 720.0 - 4.0 * lon - eqTime + tzHours * 60.0;
  double delta = radToDeg(hourAngle) * 4.0; // minutes

  double sunrise = solarNoon - delta;
  double sunset = solarNoon + delta;

  sunriseMin = (int)round(sunrise);
  sunsetMin = (int)round(sunset);
}

// Conectar a WiFi (bloqueante corto) — con depuración y limpieza previa
bool connectWiFi(const char* ssid, const char* pass, unsigned long timeoutMs = 10000) {
  if (strlen(ssid) == 0) {
    Serial.println(F("[WIFI] SSID vacío, no se intenta conectar"));
    return false;
  }
  Serial.print(F("[WIFI] Intentando conectar a SSID: "));
  Serial.println(ssid);

  WiFi.mode(WIFI_STA);
  // forzar desconexión previa y limpiar estado
  WiFi.disconnect(true);
  delay(200);

  WiFi.begin(ssid, pass);
  unsigned long start = millis();
  int lastStatus = -1;
  while ((millis() - start) < timeoutMs) {
    int s = WiFi.status();
    if (s != lastStatus) {
      lastStatus = s;
      Serial.print(F("[WIFI] status="));
      Serial.println(s);
    }
    if (s == WL_CONNECTED) {
      IPAddress ip = WiFi.localIP();
      Serial.print(F("[WIFI] Conectado, IP: "));
      Serial.println(ip);
      
      // Iniciar mDNS
      if (MDNS.begin(mdnsName)) {
        Serial.print(F("[mDNS] Iniciado: http://"));
        Serial.print(mdnsName);
        Serial.println(F(".local"));
        MDNS.addService("http", "tcp", 80);
      } else {
        Serial.println(F("[mDNS] Error al iniciar mDNS"));
      }
      
      // persistir credenciales
      prefs.begin("ilum", false);
      prefs.putString("ssid", String(ssid));
      prefs.putString("pass", String(pass));
      prefs.end();
      // sincronizar tiempo y calcular sunrise/sunset inmediatamente
      if (syncTimeAndCalculateSun()) {
        Serial.println(F("[WIFI] Hora sincronizada y sunrise/sunset calculados."));
      } else {
        Serial.println(F("[WIFI] No se pudo sincronizar la hora inmediatamente."));
      }
      // comprobar triggers inmediatos (si auto está activado)
      checkSunTriggersNow();
      // aplicar inmediatamente modo Día/Noche en base a la hora/sunrise-sunset
      applyDayNightBasedOnSun();
      return true;
    }
    delay(200);
  }

  int finalStatus = WiFi.status();
  Serial.print(F("[WIFI] No se pudo conectar. status="));
  Serial.println(finalStatus);
  const char* reason = "Desconocido";
  switch (finalStatus) {
    case WL_NO_SSID_AVAIL: reason = "SSID no disponible"; break;
    case WL_SCAN_COMPLETED: reason = "Escaneo completado (no conectado)"; break;
    case WL_CONNECT_FAILED: reason = "Fallo autenticación/conexión"; break;
    case WL_CONNECTION_LOST: reason = "Conexión perdida"; break;
    case WL_DISCONNECTED: reason = "Desconectado"; break;
    case WL_IDLE_STATUS: reason = "Idle/esperando"; break;
    default: break;
  }
  Serial.print(F("[WIFI] Razón aproximada: "));
  Serial.println(reason);
  return false;
}

// Forzar sincronización NTP y calcular sunrise/sunset para hoy
bool syncTimeAndCalculateSun() {
  if (!WiFi.isConnected()) {
    if (!connectWiFi(wifiSsid, wifiPass, 8000)) return false;
  }
  // configurar timezone offset en segundos
  long tzSecs = timezoneOffsetHours * 3600L;
  configTime(tzSecs, 0, "pool.ntp.org", "time.nist.gov");
  struct tm timeinfo;
  if (!getLocalTime(&timeinfo, 5000)) return false;
  int year = timeinfo.tm_year + 1900;
  int month = timeinfo.tm_mon + 1;
  int day = timeinfo.tm_mday;
  calculateSunriseSunset(year, month, day, locationLat, locationLon, timezoneOffsetHours, sunriseMinutes, sunsetMinutes);
  lastSunCalcDay = timeinfo.tm_yday + 1;
  sunriseTriggeredToday = false;
  sunsetTriggeredToday = false;
  Serial.print(F("[SYNC] Sunrise (min): "));
  Serial.print(sunriseMinutes);
  Serial.print(F("  Sunset (min): "));
  Serial.println(sunsetMinutes);
  return true;
}

// Estados de modo
enum Modo { MODO_DIA = 0, MODO_AMANECER = 1, MODO_NOCHE = 2, MODO_TORMENTA = 3, MODO_ANOCHECER = 4 };
Modo modoActual = MODO_NOCHE; // por defecto: modo día

const char* modoNames[] = { "Día", "Amanecer", "Noche", "Tormenta", "Anochecer" };

// prototipos relacionados con MQTT/HA discovery
void publishDiscovery();
int nameToModo(const String &name);

// Escritura segura (clamp 0..255) con optimización para evitar escrituras innecesarias
static int lastValues[4] = {-1, -1, -1, -1}; // cache de últimos valores por canal
void safeLedcWrite(int canal, int valor) {
  if (valor < 0) valor = 0;
  if (valor > 255) valor = 255;
  // Solo escribir si el valor cambió
  if (lastValues[canal] != valor) {
    ledcWrite(canal, valor);
    lastValues[canal] = valor;
  }
}

// --- Estado y variables para modo tormenta (no bloqueante)
unsigned long stormNextEvent = 0; // siguiente evento (burst) cuando no hay burst en curso
unsigned long nextFlashTime = 0;  // tiempo para el siguiente flash dentro de un burst
unsigned long flashEndTime = 0;   // fin del flash actual
bool inFlash = false;             // indicador de que hay un burst en curso
bool flashActive = false;         // indicador de que un flash está activo
int burstCount = 0;
int burstIndex = 0;
int flashColor = 0; // 0 = blanco, 1 = azul
int flashDuration = 0;
// Niveles base durante la tormenta (suaves)
const int stormBaseWhite = 0;  // mínimo blanco durante tormenta
const int stormBaseBlue = 5;   // mínimo azul durante tormenta

// --- Duración compartida para transiciones (amanecer y anochecer)
unsigned long transitionDuration = 900UL * 1000UL; // duración por defecto: 900s (15 minutos) para simular amanecer/atardecer real

// --- Estado y variables para modo amanecer (no bloqueante)
unsigned long amanecerStart = 0;
bool amanecerActive = false;
const int amanecerTargetWhite = 255;
const int amanecerTargetOrange = 255;
const int amanecerTargetWhite2 = 255;

// --- Estado y variables para modo anochecer (no bloqueante)
unsigned long anochecerStart = 0;
bool anochecerActive = false;
const int anochecerStartWhite = 255;
const int anochecerStartOrange = 255;
const int anochecerStartWhite2 = 255;
const int anochecerTargetWhite = 0;
const int anochecerTargetOrange = 0;
const int anochecerTargetWhite2 = 0;
const int anochecerTargetBlue = 5; // azul sube levemente al anochecer

void setup() {
  Serial.begin(115200);
  
  // Deshabilitar watchdog para evitar resets durante operaciones largas
  disableCore0WDT();
  
  // Configurar PWM para cada pin con mayor prioridad
  ledcSetup(canalBlanco1, frecuencia, resolucion);
  ledcAttachPin(pinBlanco1, canalBlanco1);

  ledcSetup(canalNaranja, frecuencia, resolucion);
  ledcAttachPin(pinNaranja, canalNaranja);

  ledcSetup(canalAzul, frecuencia, resolucion);
  ledcAttachPin(pinAzul, canalAzul);

  ledcSetup(canalBlanco2, frecuencia, resolucion);
  ledcAttachPin(pinBlanco2, canalBlanco2);

  // Configurar botón con pull-up y activar modo día por defecto
  pinMode(pinBoton, INPUT_PULLUP);
  modoActual = MODO_NOCHE;
  randomSeed(analogRead(0));
  // cargar credenciales guardadas (si existen)
  loadSavedWiFi();
  loadMQTTConfig();
  // cargar ubicación guardada
  prefs.begin("ilum", true);
  locationLat = prefs.getDouble("lat", 0.0);
  locationLon = prefs.getDouble("lon", 0.0);
  timezoneOffsetHours = prefs.getInt("tz", 0);
  prefs.end();
  if (strlen(wifiSsid) > 0) {
    Serial.print(F("[BOOT] Credenciales WiFi encontradas: "));
    Serial.println(wifiSsid);
    if (connectWiFi(wifiSsid, wifiPass, 8000)) {
      Serial.println(F("[BOOT] WiFi conectado (guardado)."));
      // iniciar servidor web
      setupWebServer();
      // intentar MQTT si configurado
      if (strlen(mqttHost) > 0) connectMQTT();
      // sincronizar tiempo al arranque
      syncTimeAndCalculateSun();
      // aplicar modo día/noche inmediatamente tras sincronizar
      applyDayNightBasedOnSun();
    } else {
      Serial.println(F("[BOOT] Falló la conexión con credenciales guardadas."));
      modoDia();
    }
  } else {
    modoDia();
  }
  // Mostrar el formulario/menú por Serial para pruebas
  showMenu();
}

void loop() {
  // Leer botón (INPUT_PULLUP, activo en LOW)
  int lectura = digitalRead(pinBoton);
  if (lectura != lastButtonState) {
    lastDebounceTime = millis();
  }

  if ((millis() - lastDebounceTime) > debounceDelay) {
    if (lectura != buttonState) {
      buttonState = lectura;
          if (buttonState == LOW) {
            // Ciclar entre modos: Día -> Amanecer -> Noche -> Tormenta -> Anochecer -> Día
            modoActual = (Modo)((modoActual + 1) % 5);
            if (modoActual == MODO_DIA) {
              modoDia();
              Serial.println("Modo Dia activado");
            } else if (modoActual == MODO_AMANECER) {
              enterAmanecer();
              Serial.println("Modo Amanecer activado");
            } else if (modoActual == MODO_NOCHE) {
              modoNoche();
              Serial.println("Modo Noche activado");
            } else if (modoActual == MODO_TORMENTA) {
              enterStorm();
              Serial.println("Modo Tormenta activado");
            } else {
              enterAnochecer();
              Serial.println("Modo Anochecer activado");
            }
          }
    }
  }
  lastButtonState = lectura;

  // Si estamos en modo tormenta o amanecer, ejecutar su manejador no bloqueante
  if (modoActual == MODO_TORMENTA) {
    handleStorm();
  } else if (modoActual == MODO_AMANECER) {
    handleAmanecer();
  } else if (modoActual == MODO_ANOCHECER) {
    handleAnochecer();
  }

  // manejar MQTT
  handleMQTT();

  // manejar peticiones HTTP del servidor web
  webServer.handleClient();

  // Leer comandos del formulario Serial
  handleSerialInput();
  
  // Revisión periódica para activar amanecer/anochecer automáticamente
  static unsigned long lastSunCheck = 0;
  unsigned long now = millis();
  if ((now - lastSunCheck) > 60000) { // cada minuto
    lastSunCheck = now;
    if (autoSunEnabled) {
      struct tm timeinfo;
      if (getLocalTime(&timeinfo, 2000)) {
        int today = timeinfo.tm_yday + 1;
        // si cambió el día, recalcular
        if (today != lastSunCalcDay) {
          syncTimeAndCalculateSun();
        }
        if (sunriseMinutes >= 0 && sunsetMinutes >= 0) {
          int curMin = timeinfo.tm_hour * 60 + timeinfo.tm_min;
          if (!sunriseTriggeredToday && curMin >= sunriseMinutes) {
            sunriseTriggeredToday = true;
            modoActual = MODO_AMANECER;
            enterAmanecer();
            Serial.println(F("[AUTO] Amanecer activado"));
          }
          if (!sunsetTriggeredToday && curMin >= sunsetMinutes) {
            sunsetTriggeredToday = true;
            modoActual = MODO_ANOCHECER;
            enterAnochecer();
            Serial.println(F("[AUTO] Anochecer activado"));
          }
        }
      }
    }
  }
  
  // Pequeño delay para estabilizar el loop y evitar saturación del CPU
  delay(1);
}

// MQTT loop/reconnect handling con límite de tiempo
void handleMQTT() {
  if (strlen(mqttHost) == 0) return;
  if (!mqttClient.connected()) {
    unsigned long now = millis();
    if (now - lastMqttReconnectAttempt > 5000) {
      lastMqttReconnectAttempt = now;
      if (connectMQTT()) lastMqttReconnectAttempt = 0;
    }
  } else {
    // Limitar el tiempo de procesamiento MQTT para no interferir con PWM
    mqttClient.loop();
  }
}

// 🎨 Modo noche: tonos suaves
void modoNoche() {
  safeLedcWrite(canalBlanco1, 0);
  safeLedcWrite(canalNaranja, 0);
  safeLedcWrite(canalAzul, 5);
  safeLedcWrite(canalBlanco2, 0);
}

// 🌞 Modo día: brillo máximo
void modoDia() {
  safeLedcWrite(canalBlanco1, 255);
  safeLedcWrite(canalNaranja, 255);
  safeLedcWrite(canalAzul, 0);
  safeLedcWrite(canalBlanco2, 255);
}

// Inicializar estado de amanecer
void enterAmanecer() {
  amanecerStart = millis();
  amanecerActive = true;
  // empezar desde apagado para el efecto
  safeLedcWrite(canalBlanco1, 0);
  safeLedcWrite(canalNaranja, 0);
  safeLedcWrite(canalBlanco2, 0);
  safeLedcWrite(canalAzul, 0);
}

// Manejador no bloqueante del efecto amanecer (rampa lineal)
void handleAmanecer() {
  if (!amanecerActive) return;
  unsigned long now = millis();
  unsigned long elapsed = now - amanecerStart;
  float progress = (float)elapsed / (float)transitionDuration;
  if (progress >= 1.0f) {
    // finalizar amanecer y pasar a modo día
    amanecerActive = false;
    modoActual = MODO_DIA;
    modoDia();
    Serial.println(F("[AMANECER] Completado. Modo Día activado"));
    return;
  }

  // calcular valores intermedios
  int w = (int)(amanecerTargetWhite * progress);
  int o = (int)(amanecerTargetOrange * progress);
  int w2 = (int)(amanecerTargetWhite2 * progress);

  safeLedcWrite(canalBlanco1, w);
  safeLedcWrite(canalNaranja, o);
  safeLedcWrite(canalBlanco2, w2);
}

// Inicializar estado de anochecer
void enterAnochecer() {
  anochecerStart = millis();
  anochecerActive = true;
  // empezar desde valores de día
  safeLedcWrite(canalBlanco1, anochecerStartWhite);
  safeLedcWrite(canalNaranja, anochecerStartOrange);
  safeLedcWrite(canalBlanco2, anochecerStartWhite2);
  safeLedcWrite(canalAzul, 0);
}

// Manejador no bloqueante del efecto anochecer (rampa inversa)
void handleAnochecer() {
  if (!anochecerActive) return;
  unsigned long now = millis();
  unsigned long elapsed = now - anochecerStart;
  float progress = (float)elapsed / (float)transitionDuration;
  if (progress >= 1.0f) {
    // finalizar anochecer y pasar a modo noche
    anochecerActive = false;
    modoActual = MODO_NOCHE;
    modoNoche();
    Serial.println(F("[ANOCHECER] Completado. Modo Noche activado"));
    return;
  }

  // interpolación lineal desde valores de día hacia valores de noche
  float inv = 1.0f - progress;
  int w = (int)(anochecerStartWhite * inv + anochecerTargetWhite * progress);
  int o = (int)(anochecerStartOrange * inv + anochecerTargetOrange * progress);
  int w2 = (int)(anochecerStartWhite2 * inv + anochecerTargetWhite2 * progress);
  int b = (int)(0 * inv + anochecerTargetBlue * progress);

  safeLedcWrite(canalBlanco1, w);
  safeLedcWrite(canalNaranja, o);
  safeLedcWrite(canalBlanco2, w2);
  safeLedcWrite(canalAzul, b);
}

// Inicializar estado de tormenta
void enterStorm() {
  // establecer niveles base suaves
  safeLedcWrite(canalBlanco1, stormBaseWhite);
  safeLedcWrite(canalBlanco2, stormBaseWhite);
  safeLedcWrite(canalAzul, stormBaseBlue);
  safeLedcWrite(canalNaranja, 0);

  inFlash = false;
  flashActive = false;
  burstCount = 0;
  burstIndex = 0;
  stormNextEvent = millis() + random(500, 3000);
  nextFlashTime = 0;
  flashEndTime = 0;
}

// Manejador no bloqueante del efecto de tormenta
void handleStorm() {
  unsigned long now = millis();

  if (!inFlash) {
    if (now >= stormNextEvent) {
      // Iniciar un burst de rayos
      inFlash = true;
      burstCount = random(1, 4); // 1..3 flashes
      burstIndex = 0;
      nextFlashTime = now; // empezar inmediatamente
      flashActive = false;
    } else {
      return;
    }
  }

  // Dentro de un burst
  if (!flashActive) {
    if (now >= nextFlashTime) {
      // iniciar flash
      flashColor = random(0, 2); // 0=blanco,1=azul
      flashDuration = random(40, 220);
      int intensity = random(160, 255);

      if (flashColor == 0) {
        safeLedcWrite(canalBlanco1, intensity);
        safeLedcWrite(canalBlanco2, intensity);
      } else {
        safeLedcWrite(canalAzul, intensity);
      }

      flashEndTime = now + flashDuration;
      flashActive = true;
    }
  } else {
    // estamos en un flash
    if (now >= flashEndTime) {
      // terminar flash: volver a niveles base
      safeLedcWrite(canalBlanco1, stormBaseWhite);
      safeLedcWrite(canalBlanco2, stormBaseWhite);
      safeLedcWrite(canalAzul, stormBaseBlue);

      flashActive = false;
      burstIndex++;

      if (burstIndex >= burstCount) {
        // terminar burst
        inFlash = false;
        stormNextEvent = now + random(2000, 8000); // tiempo hasta siguiente burst
        return;
      } else {
        // pausa corta antes del siguiente flash dentro del burst
        nextFlashTime = now + random(80, 600);
      }
    }
  }
}

// ------------------ Menú Serial para pruebas ------------------
void showMenu() {
  Serial.println(F("---- FORMULARIO DE PRUEBAS ----"));
  Serial.println(F("Pulse:"));
  Serial.println(F("  1 -> Modo Día"));
  Serial.println(F("  2 -> Modo Noche"));
  Serial.println(F("  3 -> Modo Tormenta"));
  Serial.println(F("  4 -> Modo Amanecer"));
  Serial.println(F("  5 -> Modo Anochecer"));
  Serial.println(F("  h -> Mostrar este menú"));
  Serial.println(F("  i -> Mostrar IP y estado WiFi"));
  Serial.println(F("  s -> Menu Ajustes (configuración)"));
  Serial.println(F("Comandos de duración:"));
  Serial.println(F("  a<segundos> -> Ajustar duración Amanecer (ej. a60)"));
  Serial.println(F("  d<segundos> -> Ajustar duración Anochecer (ej. d600)"));
  Serial.println(F("Comandos de sincronización y ubicación:"));
  Serial.println(F("  w<ssid>,<pass> -> Configurar WiFi y conectar (ej. wMiRed,clave)"));
  Serial.println(F("  l<lat>,<lon>,<tz> -> Configurar ubicación y zona (ej. l-34.6,-58.4,-3)"));
  Serial.println(F("  sync -> Forzar sincronización NTP y cálculo sunrise/sunset"));
  Serial.println(F("  auto1 -> Activar sincronización automática (usa sunrise/sunset)"));
  Serial.println(F("  auto0 -> Desactivar sincronización automática"));
  Serial.println(F("-------------------------------"));
}
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

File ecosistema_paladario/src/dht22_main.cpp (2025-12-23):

#include <Arduino.h>
#include <DHT.h>
#include <WiFi.h>
#include <WebServer.h>
#include <PubSubClient.h>

// Configuración WiFi
const char* ssid = "MiFibra";
const char* password = "rZ75dCAn";
IPAddress local_IP(192, 168, 1, 88);
IPAddress gateway(192, 168, 1, 1);
IPAddress subnet(255, 255, 255, 0);

// Configuración MQTT
const char* mqtt_server = "192.168.1.132";
const int mqtt_port = 1883;
const char* mqtt_user = "iluminacion";
const char* mqtt_password = "Thosiba2010";
const char* mqtt_base_topic = "paladario";

// Configuración del sensor DHT22
#define DHTPIN 15     // Pin D15 (GPIO 15)
#define DHTTYPE DHT22 // Tipo de sensor DHT22

// Definición de pines de relés
#define BOMBA_LLUVIA_PIN 25
#define BOMBA_CASCADA_PIN 26
#define VENTILADOR_PIN 27
#define CALEFACCION_PIN 33

DHT dht(DHTPIN, DHTTYPE);
WebServer server(80);
WiFiClient espClient;
PubSubClient mqtt(espClient);

// Variables globales
float temperatura = 0.0;
float humedad = 0.0;
bool bomba_lluvia = false;
bool bomba_cascada = false;
bool ventilador = false;
bool calefaccion = false;
bool mqtt_conectado = false;

// Declaraciones de funciones
void enviarMqttDiscovery();
void publicarEstados();

// Funciones de control de relés
void controlarBombaLluvia(bool estado) {
  digitalWrite(BOMBA_LLUVIA_PIN, estado ? HIGH : LOW);
  bomba_lluvia = estado;
  Serial.println("Bomba Lluvia: " + String(estado ? "ON" : "OFF"));
  
  // Publicar estado a MQTT
  if (mqtt_conectado) {
    mqtt.publish((String(mqtt_base_topic) + "/switch/bomba_lluvia/state").c_str(), 
                 estado ? "ON" : "OFF", true);
  }
}

void controlarBombaCascada(bool estado) {
  digitalWrite(BOMBA_CASCADA_PIN, estado ? HIGH : LOW);
  bomba_cascada = estado;
  Serial.println("Bomba Cascada: " + String(estado ? "ON" : "OFF"));
  
  if (mqtt_conectado) {
    mqtt.publish((String(mqtt_base_topic) + "/switch/bomba_cascada/state").c_str(), 
                 estado ? "ON" : "OFF", true);
  }
}

void controlarVentilador(bool estado) {
  digitalWrite(VENTILADOR_PIN, estado ? HIGH : LOW);
  ventilador = estado;
  Serial.println("Ventilador: " + String(estado ? "ON" : "OFF"));
  
  if (mqtt_conectado) {
    mqtt.publish((String(mqtt_base_topic) + "/switch/ventilador/state").c_str(), 
                 estado ? "ON" : "OFF", true);
  }
}

void controlarCalefaccion(bool estado) {
  digitalWrite(CALEFACCION_PIN, estado ? HIGH : LOW);
  calefaccion = estado;
  Serial.println("Calefacción: " + String(estado ? "ON" : "OFF"));
  
  if (mqtt_conectado) {
    mqtt.publish((String(mqtt_base_topic) + "/switch/calefaccion/state").c_str(), 
                 estado ? "ON" : "OFF", true);
  }
}

// Callback MQTT
void mqttCallback(char* topic, byte* payload, unsigned int length) {
  String message = "";
  for (unsigned int i = 0; i < length; i++) {
    message += (char)payload[i];
  }
  
  Serial.println("MQTT recibido [" + String(topic) + "]: " + message);
  
  String topicStr = String(topic);
  bool estado = (message == "ON");
  
  if (topicStr.endsWith("/bomba_lluvia/set")) {
    controlarBombaLluvia(estado);
  } else if (topicStr.endsWith("/bomba_cascada/set")) {
    controlarBombaCascada(estado);
  } else if (topicStr.endsWith("/ventilador/set")) {
    controlarVentilador(estado);
  } else if (topicStr.endsWith("/calefaccion/set")) {
    controlarCalefaccion(estado);
  }
}

// Conectar a MQTT y enviar discovery
void mqttConnect() {
  while (!mqtt.connected()) {
    Serial.print("Conectando a MQTT...");
    
    if (mqtt.connect("ESP32_Paladario", mqtt_user, mqtt_password)) {
      Serial.println(" ✓ Conectado");
      mqtt_conectado = true;
      
      // Suscribirse a topics de control
      mqtt.subscribe((String(mqtt_base_topic) + "/switch/bomba_lluvia/set").c_str());
      mqtt.subscribe((String(mqtt_base_topic) + "/switch/bomba_cascada/set").c_str());
      mqtt.subscribe((String(mqtt_base_topic) + "/switch/ventilador/set").c_str());
      mqtt.subscribe((String(mqtt_base_topic) + "/switch/calefaccion/set").c_str());
      
      // Enviar MQTT Discovery para Home Assistant
      enviarMqttDiscovery();
      
      // Publicar estados iniciales
      publicarEstados();
      
    } else {
      Serial.println(" ✗ Error, reintentando en 5s");
      mqtt_conectado = false;
      delay(5000);
    }
  }
}
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

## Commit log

2025-12-24 🔐 Añadir configuración segura con archivo separado
2025-12-24 Add Sistema de Control de Clima section with documentation links
2025-12-25 Actualiza el pinout y advertencias según definición en src/main.c. Mejora visual de tablas, diagramas y recomendaciones. Issue #PINOUT-UPDATE-2025.
